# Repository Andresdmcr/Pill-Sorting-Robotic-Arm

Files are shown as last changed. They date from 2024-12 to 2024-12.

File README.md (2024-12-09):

ArduinoArm.ino: Controls the robotic arm via serial commands from Python.

Main.py: Core script for identifying pills, detecting containers, and deciding where the pill goes based on color and position.
- Supporting Files
ColorStore.py: Captures pill images for training.
PredictLive.py: Live classification tool for testing.
RFPill.py: Trains the Random Forest model (used in the project).
SVMClassifier.py: Alternative model tested (less effective than Random Forest).
pill_classifier.pkl: Pre-trained Random Forest model for pill classification.
- 3D Models
Container.stl and Pill Holder.3mf: 3D-printed components for holding pills and containers.

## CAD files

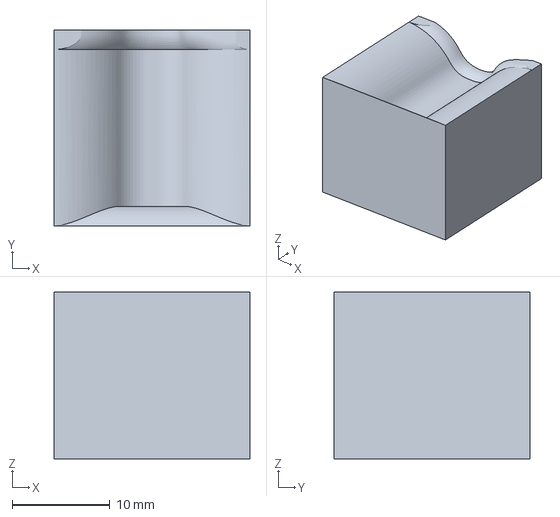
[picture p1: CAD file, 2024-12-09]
Pill Holder.3mf
20.0 x 20.0 x 17.0 mm

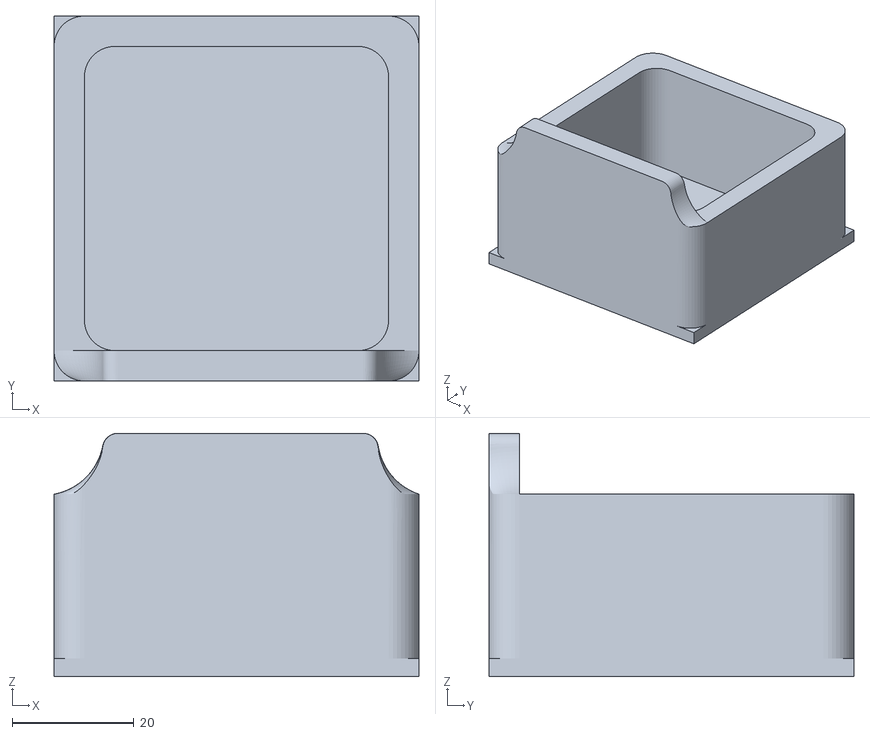
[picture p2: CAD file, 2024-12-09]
Container.stl
60.0 x 60.0 x 40.0

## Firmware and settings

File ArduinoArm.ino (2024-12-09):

#include <Wire.h>
#include <Adafruit_MotorShield.h>

Adafruit_MotorShield AFMS = Adafruit_MotorShield();
Adafruit_DCMotor *myMotor1 = AFMS.getMotor(1);  // Base
Adafruit_DCMotor *myMotor2 = AFMS.getMotor(2);  // Lift
Adafruit_DCMotor *myMotor3 = AFMS.getMotor(3);  // Arrange
Adafruit_DCMotor *myMotor4 = AFMS.getMotor(4);  // Gripper

// Motor positions
// const int M1_INIT = 804;  // Base initial
// const int M2_INIT = 447;  // Lift initial (updated)
// const int M3_INIT = 293;  // Arrange initial (updated)
// const int M4_OPEN = 535;  // Gripper open //488
// const int M4_CLOSE = 570; // Gripper closed //560


// const int M2_Pickup = 523;
// const int M3_Pickup = 385;

const int M1_INIT = 700;  // Base initial
const int M2_INIT = 512;  // Lift initial (updated)
const int M3_INIT = 157;  // Arrange initial (updated)
const int M4_OPEN = 535;  // Gripper open //488
const int M4_CLOSE = 570; // Gripper closed //560


const int M2_Pickup = 580;
const int M3_Pickup = 240;

// Position definitions for different cases (left, right, center)
const int M1_LFINAL = 630;  // Base final for left
const int M2_LFINAL = 545;   // Lift final for left
const int M3_LFINAL = 650;   // Arrange final for left

const int M1_RFINAL = 840;   // Base final for right
const int M2_RFINAL = 545;   // Lift final for right
const int M3_RFINAL = 650;   // Arrange final for right

const int M1_CFINAL = 770;   // Base final for center
const int M2_CFINAL = 545;   // Lift final for center
const int M3_CFINAL = 650;   // Arrange final for center

// Potentiometer pins
const int POT_PIN1 = A12; 
const int POT_PIN2 = A11;
const int POT_PIN3 = A10;
const int POT_PIN4 = A8;
const int TOLERANCE = 5;
 
void setup() {
  Serial.begin(9600);
  
  if (!AFMS.begin()) {
    Serial.println("Could not find Motor Shield. Check wiring.");
    while (1);
  }
  
  // Set initial speeds
  myMotor1->setSpeed(255);
  myMotor2->setSpeed(255);
  myMotor3->setSpeed(255);
  myMotor4->setSpeed(255);
  
  // Move to initial positions
  Serial.println("Moving to initial positions...");
  moveMotor(myMotor1, POT_PIN1, M1_INIT, "Base");
  moveMotor(myMotor2, POT_PIN2, M2_INIT, "Lift");
  moveMotor(myMotor3, POT_PIN3, M3_INIT, "Arrange");
  moveMotor(myMotor4, POT_PIN4, M4_OPEN, "Gripper");
  delay(2000);
}

void loop() {
  Serial.println("\n=== Waiting for Input from Python ===");

  String userInput = getPythonInput();  // Get input from Python

  if (userInput == "L") {
    moveAllMotors(M1_LFINAL, M2_LFINAL, M3_LFINAL);  // Move to final positions for left
    sendStatusToPython("Done");
  } 
  else if (userInput == "R") {
    moveAllMotors(M1_RFINAL, M2_RFINAL, M3_RFINAL);  // Move to final positions for right
    sendStatusToPython("Done");
  } 
  else if (userInput == "U") {
    moveAllMotors(M1_CFINAL, M2_CFINAL, M3_CFINAL);  // Move to final positions for center
    sendStatusToPython("Done");
  } else {
    Serial.println("Invalid input received. Please send 'L', 'R', or 'U'.");
    sendStatusToPython("Invalid");
  }

  Serial.println("\n=== Cycle Complete ===");
  delay(800); 
}

String getPythonInput() {
  while (Serial.available() == 0) {
    // Wait for input from Python script
  }

  String input = Serial.readStringUntil('\n');  // Read input until newline
  input.trim();  // Remove any leading or trailing whitespace
  Serial.print("Received input from Python: ");
  Serial.println(input);  // Print the received input for debugging
  return input;
}

void sendStatusToPython(String status) {
  Serial.print("Status: ");
  Serial.println(status);  // Send the status message back to Python
}


void moveAllMotors(int M1_FINAL, int M2_FINAL, int M3_FINAL) {
  
  // Step 1: M3 moves to final position
  Serial.println("\nStep 2: Moving arrangement");
  moveMotor(myMotor3, POT_PIN3, M3_Pickup, "Arrange");
  delay(100);

 // Step 2: M2 moves to final position
  Serial.println("\nStep 3: Moving lift");
  moveMotor(myMotor2, POT_PIN2, M2_Pickup, "Lift");
  delay(100);

  // Step 3: Gripper closes
  Serial.println("\nStep 1: Closing gripper");
  moveMotor(myMotor4, POT_PIN4, M4_CLOSE, "Gripper");
  delay(100);
  
  // Step 5: M2 moves to final position
  Serial.println("\nStep 3: Moving lift");
  moveMotor(myMotor2, POT_PIN2, M2_INIT, "Lift");
  delay(100);

  // Step 4: M3 moves to final position
  Serial.println("\nStep 2: Moving arrangement");
  moveMotor(myMotor3, POT_PIN3, M3_INIT, "Arrange");
  delay(100);
  
  // Step 6: M1 moves to final position
  Serial.println("\nStep 4: Moving base");
  moveMotor(myMotor1, POT_PIN1, M1_FINAL, "Base");
  delay(100);
  
  // Step 7: M2 moves to initial position
  Serial.println("\nStep 5: Lowering lift");
  moveMotor(myMotor2, POT_PIN2, M2_FINAL, "Lift");
  delay(100);
  
  // Step 8: M3 moves to initial position
  Serial.println("\nStep 6: Moving arrangement back");
  moveMotor(myMotor3, POT_PIN3, M3_FINAL, "Arrange");
  delay(100);
  
  // Step 10: M3 moves to initial position
  Serial.println("\nStep 8: Moving arrangement");
  moveMotor(myMotor3, POT_PIN3, M3_INIT, "Arrange");
  delay(100);
  
  // Step 11: M2 moves to initial position
  Serial.println("\nStep 9: Raising lift");
  moveMotor(myMotor2, POT_PIN2, M2_INIT, "Lift");
  delay(100);
  
  // Step 12: M1 moves to initial position
  Serial.println("\nStep 10: Moving base back");
  moveMotor(myMotor1, POT_PIN1, M1_INIT, "Base");
  delay(100);

    // Step 1: M3 moves to final position
  Serial.println("\nStep 2: Moving arrangement");
  moveMotor(myMotor3, POT_PIN3, M3_Pickup, "Arrange");
  delay(100);

 // Step 2: M2 moves to final position
  Serial.println("\nStep 3: Moving lift");
  moveMotor(myMotor2, POT_PIN2, M2_Pickup, "Lift");
  delay(100);

  // Step : Gripper opens
  Serial.println("\nStep 7: Opening gripper");
  moveMotor(myMotor4, POT_PIN4, M4_OPEN, "Gripper");
  delay(100);
  
  // Step 5: M2 moves to final position
  Serial.println("\nStep 3: Moving lift");
  moveMotor(myMotor2, POT_PIN2, M2_INIT, "Lift");
  delay(100);

  // Step 4: M3 moves to final position
  Serial.println("\nStep 2: Moving arrangement");
  moveMotor(myMotor3, POT_PIN3, M3_INIT, "Arrange");
  delay(100);
}

void moveMotor(Adafruit_DCMotor *motor, int potPin, int targetPos, String motorName) {
  int currentPos = analogRead(potPin);

  while (abs(currentPos - targetPos) > TOLERANCE) {
    currentPos = analogRead(potPin);

    Serial.print(motorName);
    Serial.print(" Position: ");
    Serial.print(currentPos);
    Serial.print(" | Target: ");
    Serial.println(targetPos);

    if (currentPos < targetPos) {
      motor->run(FORWARD);
    } else {
      motor->run(BACKWARD);
    }

    int speed = map(abs(currentPos - targetPos), 0, 512, 50, 255);
    motor->setSpeed(speed);

    delay(50);
  }

  motor->run(RELEASE);
  Serial.println(motorName + " reached position!");
}

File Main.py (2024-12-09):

import cv2 
import numpy as np
import joblib
import serial
import serial.tools.list_ports
import time

# Define HSV color ranges for containers
COLOR_RANGES = {
    'holder_green': ((35, 50, 50), (85, 255, 255)),
    'container_orange': ((5, 100, 100), (15, 255, 255)),
    'container_white': ((92, 0, 149), (137, 49, 255)),  # Previously updated values for white
    'container_blue': ((86, 191, 24), (180, 255, 255))  # Updated values for blue
}

PILL_TO_CONTAINER = {
    'pill_red': 'container_orange',
    'pill_white': 'container_white',
    'pill_silver': 'container_blue'
}

# Load the Random Forest model
model_path = r"C:\Users\andre\Downloads\pill_classifier.pkl"
try:
    clf, categories = joblib.load(model_path)
    print("Random Forest model and categories loaded successfully.")
except Exception as e:
    print(f"Error loading model: {e}")
    exit()

# Function to extract color histogram features
def extract_color_histogram(image):
    hsv = cv2.cvtColor(image, cv2.COLOR_BGR2HSV)
    hist = cv2.calcHist([hsv], [0, 1, 2], None, [8, 8, 8], [0, 180, 0, 256, 0, 256])
    return cv2.normalize(hist, hist).flatten()

# Function to classify a pill region
def classify_pill_region(roi):
    roi_resized = cv2.resize(roi, (64, 64))
    hist_features = extract_color_histogram(roi_resized).reshape(1, -1)
    probabilities = clf.predict_proba(hist_features)[0]
    predicted_class_index = np.argmax(probabilities)
    predicted_class = categories[predicted_class_index]
    confidence = probabilities[predicted_class_index]
    return predicted_class, confidence

# Function to create a mask for a specific HSV range
def create_color_mask(frame, lower_hsv, upper_hsv):
    hsv_frame = cv2.cvtColor(frame, cv2.COLOR_BGR2HSV)
    lower_bound = np.array(lower_hsv)
    upper_bound = np.array(upper_hsv)
    return cv2.inRange(hsv_frame, lower_bound, upper_bound)

# Function to find the center of the largest contour in the mask
def find_object_position(mask):
    contours, _ = cv2.findContours(mask, cv2.RETR_EXTERNAL, cv2.CHAIN_APPROX_SIMPLE)
    if contours:
        largest_contour = max(contours, key=cv2.contourArea)
        M = cv2.moments(largest_contour)
        if M['m00'] > 0:
            cx = int(M['m10'] / M['m00'])
            cy = int(M['m01'] / M['m00'])
            return (cx, cy), largest_contour
    return None, None

# Function to detect containers in the frame
def detect_containers(frame):
    containers = {}
    for name, (lower, upper) in COLOR_RANGES.items():
        if 'container' in name:
            mask = create_color_mask(frame, lower, upper)
            position, contour = find_object_position(mask)
            if position:
                containers[name] = (position, contour)
    return containers

# Function to determine relative positions of containers
def determine_relative_positions(containers):
    positions = {}
    sorted_containers = sorted(containers.items(), key=lambda item: item[1][0][0])  # Sort by x-coordinate
    if len(sorted_containers) == 3:
        positions[sorted_containers[0][0]] = "Left"
        positions[sorted_containers[1][0]] = "Up"
        positions[sorted_containers[2][0]] = "Right"
    return positions

try:
    clf, categories = joblib.load(model_path)
    print("Random Forest model and categories loaded successfully.")
except Exception as e:
    print(f"Error loading model: {e}")
    exit()

# Initialize the Arduino connection
try:
    ser = serial.Serial('COM9', 9600)  # Replace 'COM9' with your Arduino port
    time.sleep(2)  # Wait for the connection to initialize
    print("Connected to Arduino.")
except Exception as e:
    print(f"Error connecting to Arduino: {e}")
    exit()

# Function to send a command to the Arduino
def send_command_to_arduino(position):
    command = position[0].upper()  # Use the first letter of the position (e.g., 'L', 'R', 'U')
    ser.write((command + '\n').encode())
    print(f"Command sent to Arduino: {command}")

    # Wait for Arduino to complete the task
    try:
        print("Waiting for Arduino to respond...")
        start_time = time.time()
        while True:
            if ser.in_waiting > 0:  # Check if there is data in the buffer
                response = ser.readline().decode().strip()
                if response == "Done":
                    print("Arduino has completed the task.")
                    time.sleep(2)  # Wait 2 seconds before processing the next pill
                    break
                else:
                    print(f"Unexpected response from Arduino: {response}")
            if time.time() - start_time > 60:  # Timeout after 60 seconds
                print("Timeout waiting for Arduino. Moving to the next pill.")
                break
    except Exception as e:
        print(f"Error communicating with Arduino: {e}")
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
